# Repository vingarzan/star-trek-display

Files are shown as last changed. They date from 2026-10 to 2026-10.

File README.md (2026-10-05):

# Star Trek wall display

Current design: **v42 — 5 mm peg for an 8.5 mm-deep hole**.

- [Latest print files, notes and previews](outputs/)
- [Geometry checks](outputs/geometry_checks.json)
- [Version history and tagged archives](VERSIONS.md)
- [Artifact checksums](manifest.json)

Only the latest version files are kept on main. ZIP files are not tracked. Earlier designs remain accessible through Git commits and version tags.

All eight hexagon variants now have the original inner-edge title-holder recess filled with solid material. External interlocking connectors retain their geometry. See the [notch detail](outputs/filled_title_notch_preview.png). Run `work/fill_title_notches.py` after regenerating any older frame geometry.

A [5 mm peg insert](outputs/peg_insert_5mm.stl) is included for the 8.5 mm-deep ship hole. Its straight shaft is 8 mm long, with a 2 mm rounded shoulder and the same removable base as the existing inserts. Try the [5 mm diameter fit test](outputs/fit_test_peg_5.0mm.stl) first.

The [nail cover](outputs/nail_cover_cap.stl) now sits flush in the side-braced mount’s 3 mm recess. Its skirt is wider and its slotted grip bumps have 0.15 mm interference per side. Use a head no larger than 9 mm diameter and 2 mm above the recess floor. Print [fit_test_nail_cover.stl](outputs/fit_test_nail_cover.stl) to check the fit; physical grip remains untested. See the [preview](outputs/nail_cover_preview.png).

The [lighter corner-braced arm](outputs/hex_ship_corner_braced_light_arm.stl) removes the 5-degree outward socket and retains the upward socket at its original 130 mm clearance from the frame front. It has a centred 38 mm-wide base, an arm approximately 17 mm wide near its base and a 20 × 20 mm socket housing, and a rounded tip at 147 mm from the wall. Solid-model volume is 44.9% lower than the dual-socket corner-braced version; actual filament savings depend on slicing. Both existing peg inserts still fit geometrically. The original variants remain available. See the [preview](outputs/light_arm_preview.png). Strength of this slimmer variant is not physically validated.

For the smaller Galaxy plaque, use [hex_plaque_galaxy_4.7mm.stl](outputs/hex_plaque_galaxy_4.7mm.stl) and [plaque_retainer_galaxy_4.7mm.stl](outputs/plaque_retainer_galaxy_4.7mm.stl). It has bottom-centre, lower-left and lower-right clips and an upper-right removable retainer (M2.5 × 12 mm screw). The gap is 4.9 mm for the measured 4.7 mm plaque. The holder pilot is 2.35 mm and the retainer clearance hole is 3.1 mm, splitting the difference between the previous sizes and the proposed M2.5 sizes. The retainer position and body are unchanged from v39. The larger plaque holders retain their existing holes. See the [Galaxy preview](outputs/galaxy_holder_preview.png). The older generic 4.7 mm holder has the larger Sovereign outline and is not the Galaxy holder.

The [corner-braced arm mount](outputs/hex_ship_corner_braced_arm.stl) is a parallel option to the original side-braced arm mount. Three 12 × 8 mm braces connect opposite corners. The inner hexagon is centred and measures 96 × 83.14 × 8 mm, supporting the rounded arm joint. The vertical nail brace is removed and the nail tab matches the plain open hexagon. The arm, peg sockets and outer connectors are preserved. The existing nail cover is intended for the side-braced mount, not this restored tab. See the [preview](outputs/corner_braced_arm_preview.png). Geometry is checked; physical strength has not been tested.

An additional [empty hexagon](outputs/hex_empty_original_size.stl) preserves the original 210 × 185.865 × 8 mm frame and interlocking connectors, with no nail tab or internal supports. Print flat at 100% scale. The existing open frame with nail tab remains available.

The current inserts have identical 10.3 mm square stems, rounded shoulders and 0.15 mm nominal bottom clearance at bolt alignment. Pin-free retention relies on tested physical friction. The 8 mm round peg has 19 mm engagement; the 6 mm peg has 10 mm engagement. Snug plaque-holder/latch sets are included for 5.7 mm and 4.7 mm plates.

Dimensions are millimetres. Print at 100% scale. Geometry checks do not establish physical fit or load capacity. See assembly notes and print the relevant fit tests first.

`source_models` contains the supplied reference meshes. `work` contains the current peg generator, renderer, packaging script and shared rendering helper. Paths stay stable across versions; Git commits and tags identify each revision.

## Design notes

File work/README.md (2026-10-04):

# Current supporting scripts

Run from the repository root with Python, numpy, scipy, trimesh, manifold3d and matplotlib available.

- `build.py` regenerates the peg inserts against the current arm and geometry report in outputs; it does not rebuild the entire display system.
- `render_pegs.py` renders the current inserts using the shared `render.py` helper.
- `package.py` validates the insert interfaces, generates fit samples and creates an ignored local ZIP from current outputs. Assembly notes are maintained separately.

These scripts operate on the current outputs directly. Historical complete design workflows remain in older Git commits and tags. No version numbers are used in current filenames or output-directory paths.

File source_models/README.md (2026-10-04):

Original user-supplied reference STL files used to derive the mounts. Original authorship and licensing are not established by this archive; no new license is asserted for these files.

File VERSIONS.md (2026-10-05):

# Version history

These commits import the saved design iterations in order. Commit dates reflect the upload, not the original design time. Each version has a matching Git tag. Historical artifacts remain available through the version tags; only the latest version is retained on main. Early versions are superseded prototypes.

| Version | Change | Outputs |
| --- | --- | --- |
| [v1](https://github.com/vingarzan/star-trek-display/tree/v1) | Initial inclined ship mount | [files](https://github.com/vingarzan/star-trek-display/tree/v1/outputs/) |
| [v2](https://github.com/vingarzan/star-trek-display/tree/v2) | Enlarged hexagon and removable peg inserts | [files](https://github.com/vingarzan/star-trek-display/tree/v2/outputs/v2) |
| [v3](https://github.com/vingarzan/star-trek-display/tree/v3) | Dual sockets and 130 mm level-flight arm | [files](https://github.com/vingarzan/star-trek-display/tree/v3/outputs/v3) |
| [v4](https://github.com/vingarzan/star-trek-display/tree/v4) | Separate decorative plaque hanger | [files](https://github.com/vingarzan/star-trek-display/tree/v4/outputs/v4) |
| [v5](https://github.com/vingarzan/star-trek-display/tree/v5) | Modular square tile layout | [files](https://github.com/vingarzan/star-trek-display/tree/v5/outputs/v5) |
| [v6](https://github.com/vingarzan/star-trek-display/tree/v6) | Original-size interlocking hexagons | [files](https://github.com/vingarzan/star-trek-display/tree/v6/outputs/v6) |
| [v7](https://github.com/vingarzan/star-trek-display/tree/v7) | No-drill decorative plaque clips | [files](https://github.com/vingarzan/star-trek-display/tree/v7/outputs/v7) |
| [v8](https://github.com/vingarzan/star-trek-display/tree/v8) | Raise plaque and refine clip placement | [files](https://github.com/vingarzan/star-trek-display/tree/v8/outputs/v8) |
| [v9](https://github.com/vingarzan/star-trek-display/tree/v9) | Original nail tab and simplified frames | [files](https://github.com/vingarzan/star-trek-display/tree/v9/outputs/v9) |
| [v10](https://github.com/vingarzan/star-trek-display/tree/v10) | Flush plaque clips without upper latch | [files](https://github.com/vingarzan/star-trek-display/tree/v10/outputs/v10) |
| [v11](https://github.com/vingarzan/star-trek-display/tree/v11) | Integrated rounded arm and hexagon | [files](https://github.com/vingarzan/star-trek-display/tree/v11/outputs/v11) |
| [v12](https://github.com/vingarzan/star-trek-display/tree/v12) | Move plaque clips to lower corners | [files](https://github.com/vingarzan/star-trek-display/tree/v12/outputs/v12) |
| [v13](https://github.com/vingarzan/star-trek-display/tree/v13) | Narrow clips and upper-right plaque latch | [files](https://github.com/vingarzan/star-trek-display/tree/v13/outputs/v13) |
| [v14](https://github.com/vingarzan/star-trek-display/tree/v14) | Compact flat arm base | [files](https://github.com/vingarzan/star-trek-display/tree/v14/outputs/v14) |
| [v15](https://github.com/vingarzan/star-trek-display/tree/v15) | Hexagonal arm base outline | [files](https://github.com/vingarzan/star-trek-display/tree/v15/outputs/v15) |
| [v16](https://github.com/vingarzan/star-trek-display/tree/v16) | Extended base edges and outward chamfer | [files](https://github.com/vingarzan/star-trek-display/tree/v16/outputs/v16) |
| [v17](https://github.com/vingarzan/star-trek-display/tree/v17) | Rounded arm-root reinforcement | [files](https://github.com/vingarzan/star-trek-display/tree/v17/outputs/v17) |
| [v18](https://github.com/vingarzan/star-trek-display/tree/v18) | Diagonal frame braces | [files](https://github.com/vingarzan/star-trek-display/tree/v18/outputs/v18) |
| [v19](https://github.com/vingarzan/star-trek-display/tree/v19) | Match lower fillet to angled brace | [files](https://github.com/vingarzan/star-trek-display/tree/v19/outputs/v19) |
| [v20](https://github.com/vingarzan/star-trek-display/tree/v20) | Central hexagon and nail-tab bridge | [files](https://github.com/vingarzan/star-trek-display/tree/v20/outputs/v20) |
| [v21](https://github.com/vingarzan/star-trek-display/tree/v21) | Fill nail-adapter recess | [files](https://github.com/vingarzan/star-trek-display/tree/v21/outputs/v21) |
| [v22](https://github.com/vingarzan/star-trek-display/tree/v22) | Smaller central hexagon | [files](https://github.com/vingarzan/star-trek-display/tree/v22/outputs/v22) |
| [v23](https://github.com/vingarzan/star-trek-display/tree/v23) | Recessed nail seat and removable cap | [files](https://github.com/vingarzan/star-trek-display/tree/v23/outputs/v23) |
| [v24](https://github.com/vingarzan/star-trek-display/tree/v24) | Uniform 12 mm frame braces | [files](https://github.com/vingarzan/star-trek-display/tree/v24/outputs/v24) |
| [v25](https://github.com/vingarzan/star-trek-display/tree/v25) | Disk-free 8 mm and 6 mm inserts; sort fit tests | [files](https://github.com/vingarzan/star-trek-display/tree/v25/outputs/v25) |

| [v26](https://github.com/vingarzan/star-trek-display/tree/v26) | Round conical peg transitions; snug 5.7 mm and 4.7 mm plaque sets | [files](https://github.com/vingarzan/star-trek-display/tree/v26/outputs/v26) |
| [v27](https://github.com/vingarzan/star-trek-display/tree/v27) | Curved peg transitions; 6 mm transition shortened to 2 mm | [files](https://github.com/vingarzan/star-trek-display/tree/v27/outputs/v27) |
| [v28](https://github.com/vingarzan/star-trek-display/tree/v28) | Identical square bases; 6 mm round shaft shortened to 10 mm | [files](https://github.com/vingarzan/star-trek-display/tree/v28/outputs/v28) |
| [v29](https://github.com/vingarzan/star-trek-display/tree/v29) | Snug stems; 0.15 mm nominal bottom gap; optional pin and fit samples | [files](https://github.com/vingarzan/star-trek-display/tree/v29/outputs/v29) |

v4 contains the saved plaque-hanger experiment; v9 has saved meshes and checks but no standalone notes or preview. No missing historical files were fabricated.

| [v30](https://github.com/vingarzan/star-trek-display/tree/v30) | Add empty original-size hexagon without nail tab or internal supports | [files](https://github.com/vingarzan/star-trek-display/tree/v30/outputs/) |

| [v31](https://github.com/vingarzan/star-trek-display/tree/v31) | Add parallel integrated arm variant with corner-to-corner braces | [files](https://github.com/vingarzan/star-trek-display/tree/v31/outputs/) |

| [v32](https://github.com/vingarzan/star-trek-display/tree/v32) | Fill internal title-holder notch on all six hexagon variants | [files](https://github.com/vingarzan/star-trek-display/tree/v32/outputs/) |

| [v33](https://github.com/vingarzan/star-trek-display/tree/v33) | Centre and resize corner-braced base, remove vertical nail brace, restore original nail tab | [files](https://github.com/vingarzan/star-trek-display/tree/v33/outputs/) |

| [v34](https://github.com/vingarzan/star-trek-display/tree/v34) | Add Galaxy plaque holder with three lower clips and upper-right retainer | [files](https://github.com/vingarzan/star-trek-display/tree/v34/outputs/) |

| [v35](https://github.com/vingarzan/star-trek-display/tree/v35) | Add lighter corner-braced arm with single upward socket and smaller centred base | [files](https://github.com/vingarzan/star-trek-display/tree/v35/outputs/) |

| [v36](https://github.com/vingarzan/star-trek-display/tree/v36) | Narrow single-socket arm to about 17–20 mm while preserving 130 mm clearance | [files](https://github.com/vingarzan/star-trek-display/tree/v36/outputs/) |

| [v37](https://github.com/vingarzan/star-trek-display/tree/v37) | Reduce arm cross-section height and central base to 52 mm, preserving 130 mm clearance | [files](https://github.com/vingarzan/star-trek-display/tree/v37/outputs/) |

| [v38](https://github.com/vingarzan/star-trek-display/tree/v38) | Reduce light arm central hexagon from 52 to 38 mm wide, retaining full joint support | [files](https://github.com/vingarzan/star-trek-display/tree/v38/outputs/) |

| [v39](https://github.com/vingarzan/star-trek-display/tree/v39) | Match Galaxy retainer holes to larger holder: 2.6 mm pilot and 3.4 mm clearance; widen and reposition retainer | [files](https://github.com/vingarzan/star-trek-display/tree/v39/outputs/) |

| [v40](https://github.com/vingarzan/star-trek-display/tree/v40) | Set Galaxy pilot to 2.35 mm and retainer clearance to 3.1 mm for user-selected intermediate fit | [files](https://github.com/vingarzan/star-trek-display/tree/v40/outputs/) |

| [v41](https://github.com/vingarzan/star-trek-display/tree/v41) | Make nail cover flush at 3 mm total height, widen skirt and increase grip interference | [files](https://github.com/vingarzan/star-trek-display/tree/v41/outputs/) |

| [v42](https://github.com/vingarzan/star-trek-display/tree/v42) | Add 5 mm peg with 8 mm shaft for an 8.5 mm-deep hole, plus diameter fit test | [files](https://github.com/vingarzan/star-trek-display/tree/v42/outputs/) |

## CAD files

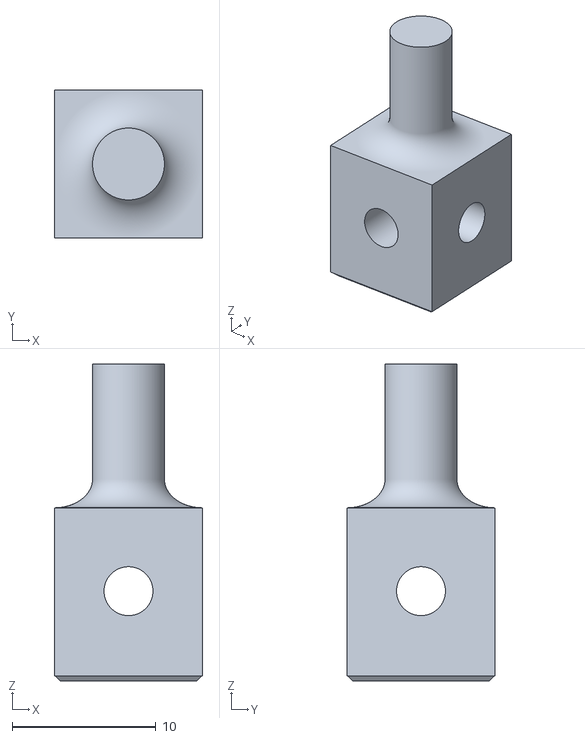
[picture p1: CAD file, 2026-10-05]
outputs/peg_insert_5mm.stl
10.3 x 10.3 x 22.0

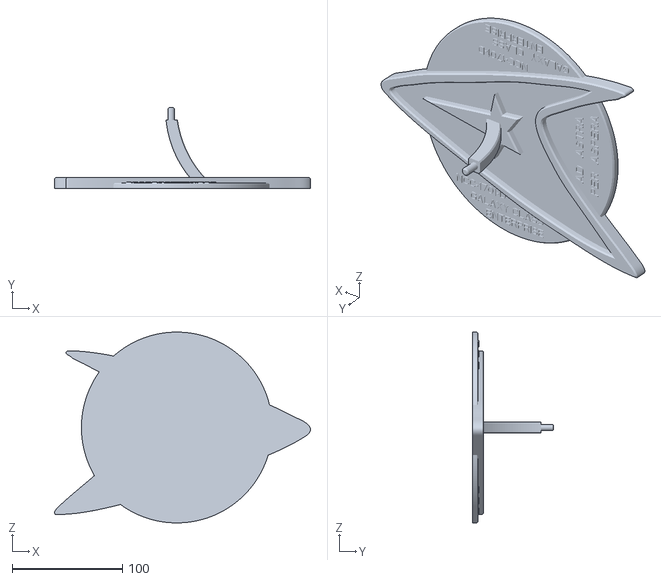
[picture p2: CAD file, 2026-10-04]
source_models/xxx_-_stand_galaxy_d.stl
232.4 x 73.5 x 173.2

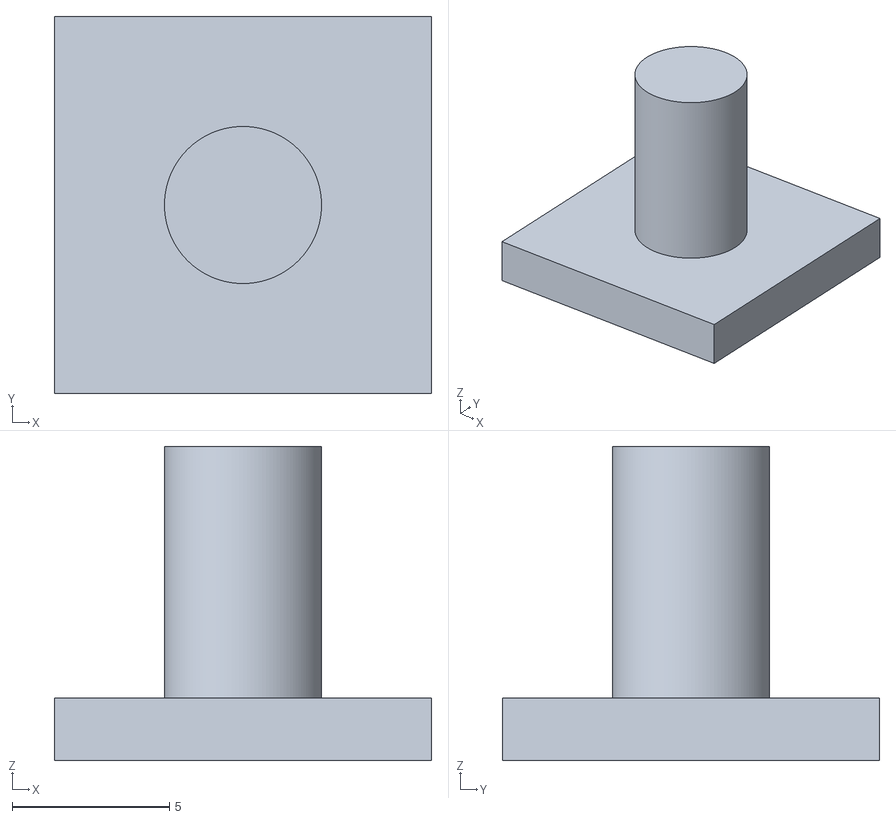
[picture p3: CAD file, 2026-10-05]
outputs/fit_test_peg_5.0mm.stl
12.0 x 12.0 x 10.0

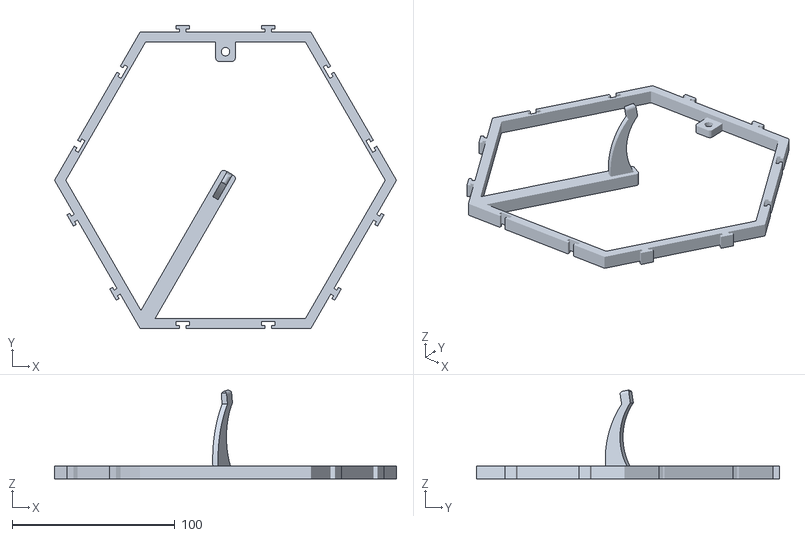
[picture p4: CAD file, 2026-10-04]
source_models/obj_2_Inclined display with nail.stl
210.0 x 185.9 x 54.6

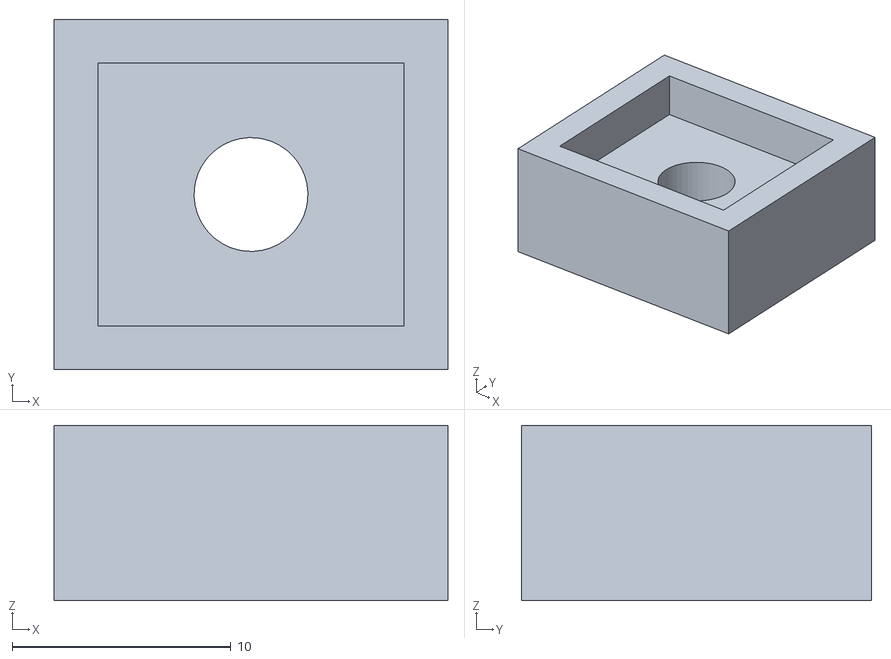
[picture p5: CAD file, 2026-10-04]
outputs/fit_test_nail_cover.stl
18.0 x 16.0 x 8.00

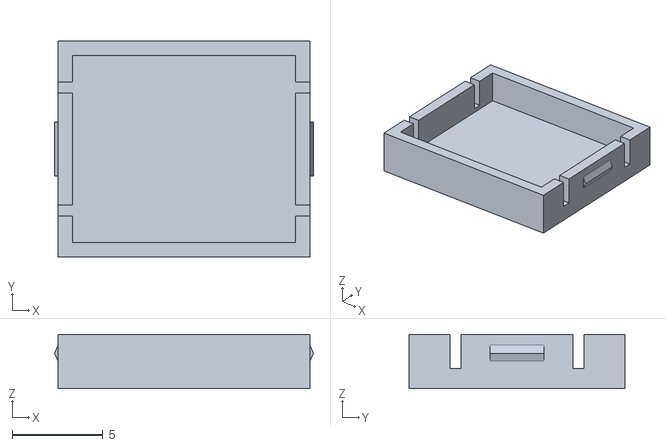
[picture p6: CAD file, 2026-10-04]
outputs/nail_cover_cap.stl
14.3 x 11.9 x 3.00

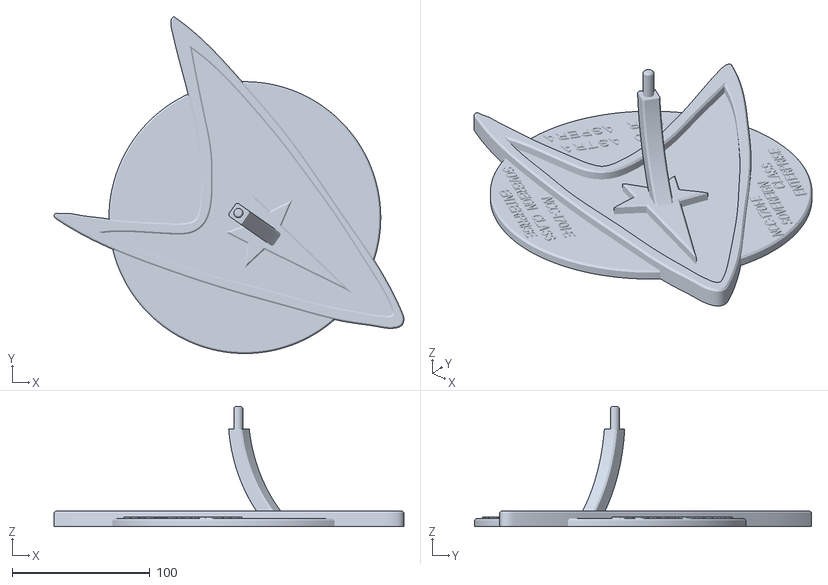
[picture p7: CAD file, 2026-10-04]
source_models/xxx_-_stand_sovereign_d.stl
254.1 x 244.8 x 87.3

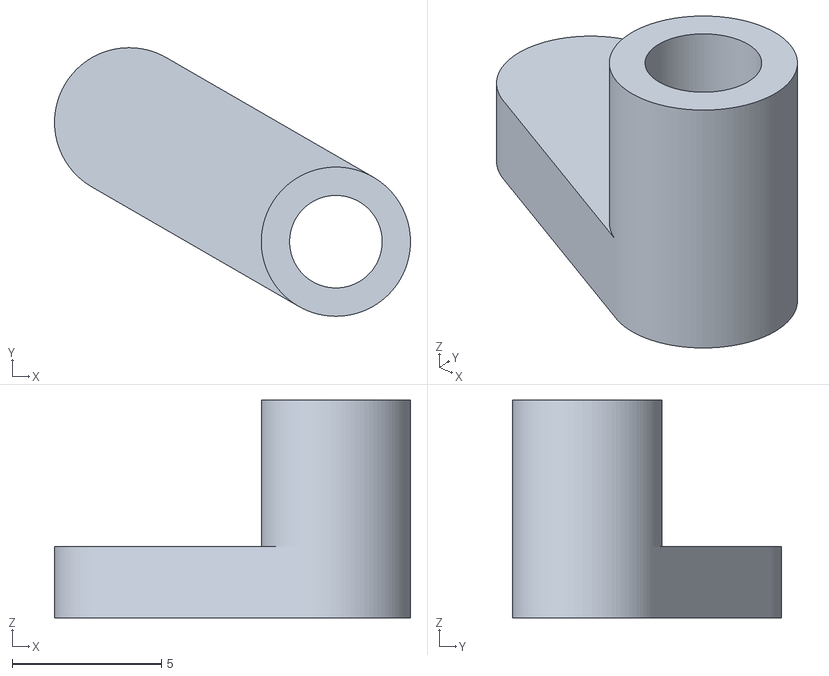
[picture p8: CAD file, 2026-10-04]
outputs/plaque_retainer_galaxy_4.7mm.stl
11.9 x 9.00 x 7.30

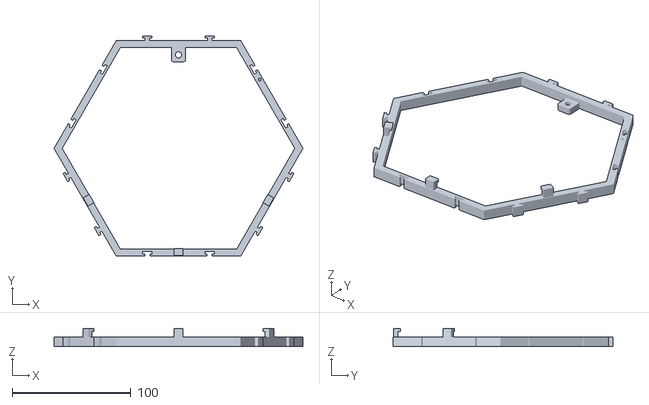
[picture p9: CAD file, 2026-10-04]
outputs/hex_plaque_galaxy_4.7mm.stl
210.0 x 185.9 x 15.3

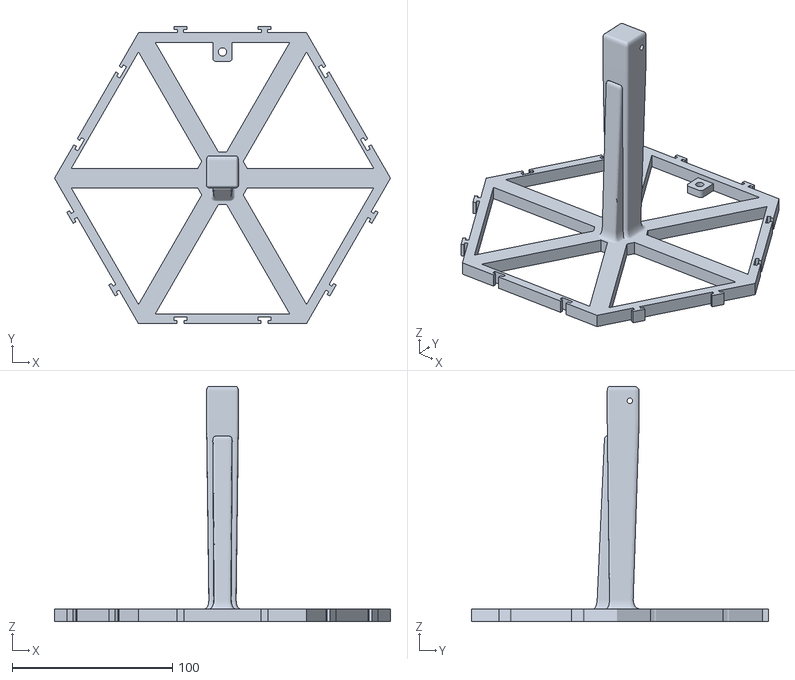
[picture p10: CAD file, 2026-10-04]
outputs/hex_ship_corner_braced_light_arm.stl
210.0 x 185.9 x 147.0

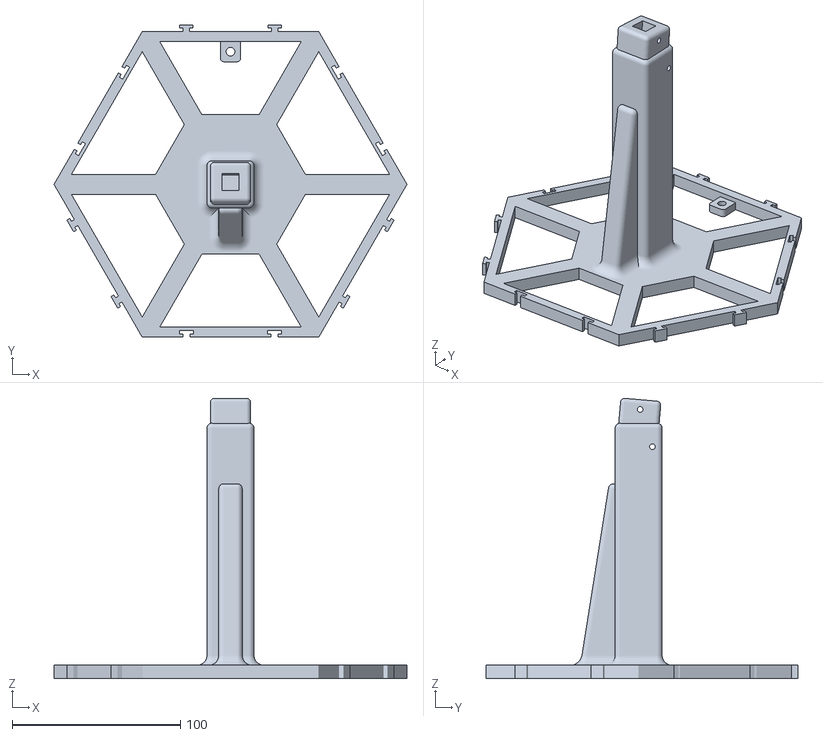
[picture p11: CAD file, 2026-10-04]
outputs/hex_ship_corner_braced_arm.stl
210.0 x 185.9 x 166.8

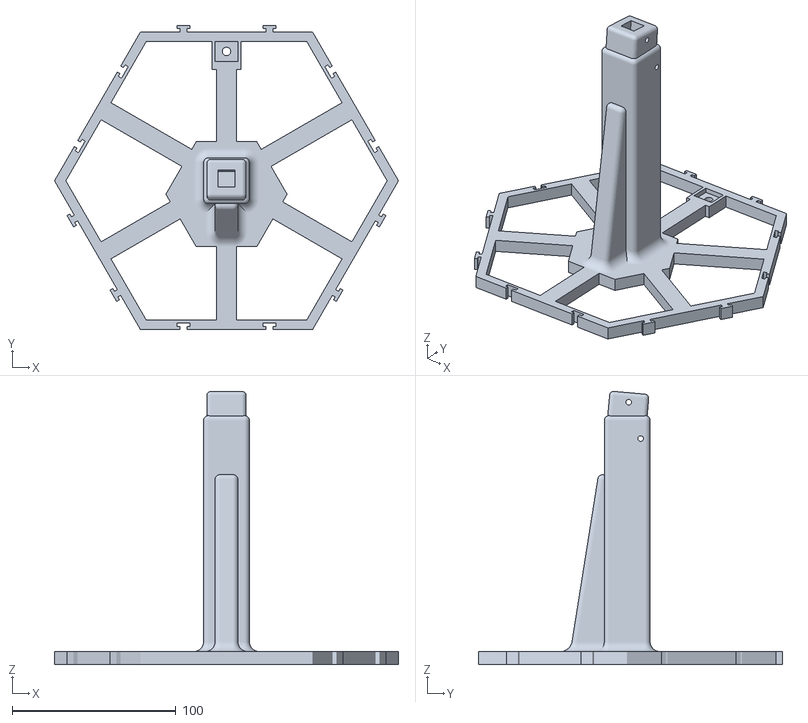
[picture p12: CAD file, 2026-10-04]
outputs/hex_ship_integrated_rounded_arm.stl
210.0 x 185.9 x 166.8

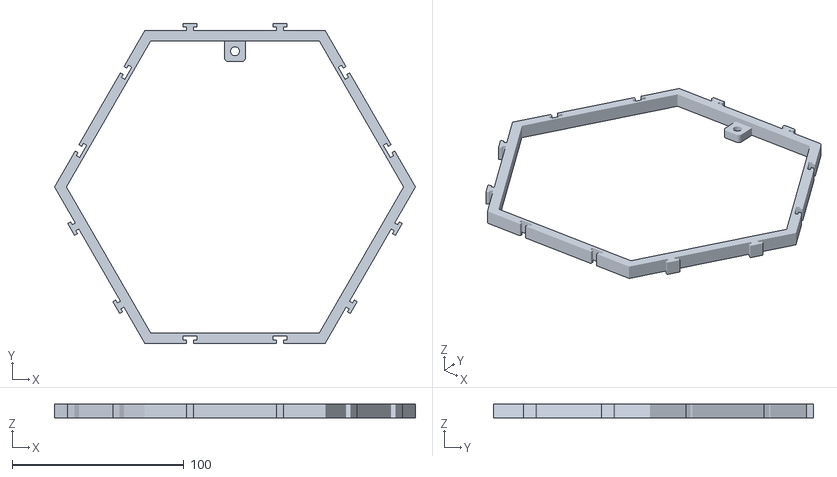
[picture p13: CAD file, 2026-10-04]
outputs/hex_open_original_size.stl
210.0 x 185.9 x 8.00

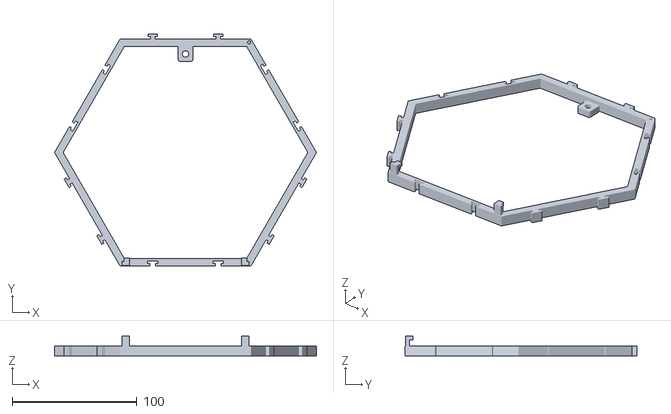
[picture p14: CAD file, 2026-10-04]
outputs/hex_plaque_snug_4.7mm.stl
210.0 x 185.9 x 15.9

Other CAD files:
source_models/obj_1_Inclined display.stl
outputs/hex_plaque_snug_5.7mm.stl
outputs/hex_empty_original_size.stl
outputs/fit_test_arm_stem_10.3mm.stl
outputs/fit_test_arm_stem_10.2mm.stl
outputs/fit_test_arm_stem_10.4mm.stl
outputs/fit_test_original_joint_bottom.stl
outputs/fit_test_original_joint_top.stl
outputs/fit_test_peg_6.0mm.stl
outputs/fit_test_peg_7.7mm.stl
outputs/fit_test_peg_7.8mm.stl
outputs/fit_test_peg_7.9mm.stl
outputs/fit_test_peg_8.0mm.stl
outputs/fit_test_plate_gap_4.7mm.stl
outputs/fit_test_plate_gap_5.7mm.stl
outputs/fit_test_socket.stl
outputs/peg_insert_6mm.stl
outputs/peg_insert_8mm.stl
outputs/plaque_latch_snug_4.7mm.stl
outputs/plaque_latch_snug_5.7mm.stl

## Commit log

2026-10-04 v9: Original nail tab and simplified frames
    [B_dual_socket_arm_130mm.stl, hex_open_original_size.stl, hex_plaque_clip_cradle.stl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]
2026-10-04 v8: Raise plaque and refine clip placement
    [B_dual_socket_arm_130mm.stl, hex_open_original_size.stl, hex_plaque_clip_cradle.stl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]
2026-10-04 v7: No-drill decorative plaque clips
    [B_dual_socket_arm_130mm.stl, hex_open_original_size.stl, hex_plaque_clip_cradle.stl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]
2026-10-04 v6: Original-size interlocking hexagons
    [B_dual_socket_arm_130mm.stl, hex_open_original_size.stl, hex_plaque_upright_original_size.stl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]
2026-10-04 v5: Modular square tile layout
    [B_dual_socket_arm_130mm.stl, peg_fit_7.7mm.stl, peg_fit_7.8mm.stl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]
2026-10-04 v4: Separate decorative plaque hanger
    [plaque_drilling_template.stl, plaque_hidden_hanger.stl]
2026-10-04 v3: Dual sockets and 130 mm level-flight arm
    [A_hex_carrier_244mm.stl, B_dual_socket_arm_130mm.stl, drilling_template.stl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]
2026-10-04 v2: Enlarged hexagon and removable peg inserts
    [A_hex_carrier_244mm.stl, B_arm_and_two_inserts_layout.stl, B_socket_arm_5deg_up.stl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]
2026-10-04 v11: Integrated rounded arm and hexagon
    [hex_open_original_size.stl, hex_plaque_flush_clips.stl, hex_ship_integrated_rounded_arm.stl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]
2026-10-04 v10: Flush plaque clips without upper latch
    [B_dual_socket_arm_130mm.stl, hex_open_original_size.stl, hex_plaque_flush_clips.stl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]
2026-10-04 v1: Initial inclined ship mount
    [A_hex_carrier.stl, B_arm_5deg_up.stl, drilling_template.stl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]
2026-10-04 v23: Recessed nail seat and removable cap
    [hex_open_original_size.stl, hex_plaque_flush_clips.stl, hex_ship_integrated_rounded_arm.stl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]
2026-10-04 v22: Smaller central hexagon
    [hex_open_original_size.stl, hex_plaque_flush_clips.stl, hex_ship_integrated_rounded_arm.stl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]
2026-10-04 v21: Fill nail-adapter recess
    [hex_open_original_size.stl, hex_plaque_flush_clips.stl, hex_ship_integrated_rounded_arm.stl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]
2026-10-04 v20: Central hexagon and nail-tab bridge
    [hex_open_original_size.stl, hex_plaque_flush_clips.stl, hex_ship_integrated_rounded_arm.stl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]
2026-10-04 v19: Match lower fillet to angled brace
    [hex_open_original_size.stl, hex_plaque_flush_clips.stl, hex_ship_integrated_rounded_arm.stl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]
2026-10-04 v18: Diagonal frame braces
    [hex_open_original_size.stl, hex_plaque_flush_clips.stl, hex_ship_integrated_rounded_arm.stl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]
2026-10-04 v17: Rounded arm-root reinforcement
    [hex_open_original_size.stl, hex_plaque_flush_clips.stl, hex_ship_integrated_rounded_arm.stl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]
2026-10-04 v16: Extended base edges and outward chamfer
    [hex_open_original_size.stl, hex_plaque_flush_clips.stl, hex_ship_integrated_rounded_arm.stl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]
2026-10-04 v15: Hexagonal arm base outline
    [hex_open_original_size.stl, hex_plaque_flush_clips.stl, hex_ship_integrated_rounded_arm.stl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]
2026-10-04 v14: Compact flat arm base
    [hex_open_original_size.stl, hex_plaque_flush_clips.stl, hex_ship_integrated_rounded_arm.stl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]
2026-10-04 v13: Narrow clips and upper-right plaque latch
    [hex_open_original_size.stl, hex_plaque_flush_clips.stl, hex_ship_integrated_rounded_arm.stl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]
2026-10-04 v12: Move plaque clips to lower corners
    [hex_open_original_size.stl, hex_plaque_flush_clips.stl, hex_ship_integrated_rounded_arm.stl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]
2026-10-04 v24: Uniform 12 mm frame braces
    [hex_open_original_size.stl, hex_plaque_flush_clips.stl, hex_ship_integrated_rounded_arm.stl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]
2026-10-04 v25: Disk-free 8 mm and 6 mm inserts; sort fit tests
    [fit_test_nail_cover.stl, fit_test_original_joint_bottom.stl, fit_test_original_joint_top.stl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]
2026-10-04 v26: Round conical peg transitions and snug 5.7 mm and 4.7 mm plaque sets
    [fit_test_nail_cover.stl, fit_test_original_joint_bottom.stl, fit_test_original_joint_top.stl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]
2026-10-04 v27: Round peg transitions and shorten the 6 mm fillet
    [fit_test_nail_cover.stl, fit_test_original_joint_bottom.stl, fit_test_original_joint_top.stl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]
2026-10-04 v28: Match square peg bases and shorten the 6 mm shaft
    [fit_test_nail_cover.stl, fit_test_original_joint_bottom.stl, fit_test_original_joint_top.stl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]
2026-10-04 v29: Snug removable stems with reduced bottom clearance and optional pin
    [fit_test_arm_stem_10.2mm.stl, fit_test_arm_stem_10.3mm.stl, fit_test_arm_stem_10.4mm.stl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]
2026-10-04 Keep only latest version artifacts and stop tracking ZIP archives
    [A_hex_carrier.stl, A_hex_carrier_244mm.stl, B_arm_5deg_up.stl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]
2026-10-04 Flatten current outputs and use stable artifact and script paths
    [fit_test_arm_stem_10.2mm.stl, fit_test_arm_stem_10.3mm.stl, fit_test_arm_stem_10.4mm.stl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]
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2026-10-04 Fill internal title-holder recess on all hexagon variants
    [hex_empty_original_size.stl, hex_open_original_size.stl, hex_plaque_snug_4.7mm.stl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]
2026-10-04 Centre corner-braced base and restore original nail tab
    [hex_ship_corner_braced_arm.stl]
2026-10-04 Add smaller Galaxy plaque holder with three clips and upper retainer
    [hex_plaque_galaxy_4.7mm.stl, plaque_retainer_galaxy_4.7mm.stl, xxx_-_stand_galaxy_d.stl]
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2026-10-04 Narrow light arm while retaining 130 mm clearance
    [hex_ship_corner_braced_light_arm.stl]
2026-10-04 Reduce arm section height and shrink centred base
    [hex_ship_corner_braced_light_arm.stl]
2026-10-04 Reduce light arm central hexagon to 38 mm
    [hex_ship_corner_braced_light_arm.stl]
2026-10-04 Match Galaxy retainer holes to larger plaque holder
    [hex_plaque_galaxy_4.7mm.stl, plaque_retainer_galaxy_4.7mm.stl]
2026-10-04 Use intermediate Galaxy screw-hole sizes for M2.5 fit
    [hex_plaque_galaxy_4.7mm.stl, plaque_retainer_galaxy_4.7mm.stl]
2026-10-04 Make nail cover flush and tighten its friction fit
    [fit_test_nail_cover.stl, nail_cover_cap.stl]
2026-10-05 Add 5 mm peg for 8.5 mm-deep ship socket
    [fit_test_peg_5.0mm.stl, peg_insert_5mm.stl]
